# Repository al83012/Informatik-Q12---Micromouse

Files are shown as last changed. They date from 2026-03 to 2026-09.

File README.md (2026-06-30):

# Informatik-Q12---Micromouse

## Ziel
Als Teil des Lehrplans des Leistungsfachs Informatik ist in der Q12 ein Gruppenprojekt vorgesehen. 

Wir haben dafür das Thema `Micromouse` gewählt, versuchen also ein unbekanntes Labyrinth möglichst schnell mit einem kleinen Roboter zu lösen.

## Aufbau
Da es sich hierbei um ein Gruppenprojekt handelt, haben wir uns dafür entschieden, nicht dem typischen Ansatz für Micromice zu folgen und stattdessen das Projekt über mehrere Geräte aufzuteilen. Dadurch ergeben sich Grob 4 Arbeitsbereiche für dieses Projekt:

### Elektronik
- Das Design der Micromouse selbst
- PCB-Erstellung
- Komponenten Wahl und Zusammenbau

### Micromouse Programmierung
- Steuercode der Motoren
- Verarbeitung von Befehlen
- Lokalisierung

### Backend Programmierung
- Kommunikation mit Frontend und Micromouse
- Anwenden bestimmter Lösungsstrategien
- Vorausplanung zur Reduktion von Kommunikation und Latenz
- Erkennen von Mess- und Bedienungsfehlern

### Frontend Programmierung
- Darstellung des Projekts mithilfe einer Website
- Darstellung der Backend-Prozesse
- Eingabe für Lösungsstrategien und Nutzer-Befehlen

### Sponsoring
Wir möchten uns außerdem herzlichst bei den folgenden Sponsoren bedanken:

`Dr. Fritz Faulhaber GmbH & Co. KG` Für das Bereitstellen der Motoren. <br>
`JLCPCB` Für das Bereitstellen der PCBs

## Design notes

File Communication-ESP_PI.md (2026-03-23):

Generell
- WiFi host = Raspberry Pi, kein externes WiFi
- MQTT broker = Mosquitto auf dem Pi
- Pi selbst --> Hostet zwar broker, ist aber auch Client
- Keine Nachricht darf auf das ankommen von Nachrichten in anderen Kanälen angewiesen sein
- QoS 2, um Ordnung innerhalb von Kanälen zu garantieren, und Befehlsanzahl einzuhalten --> Aber: Höhere Latenz

Raspberry Pi
- Auto-startup --> Std Port 1883 --> unverschlüsselt reicht
- hostapd --> Pi als Access Point konfigurieren
  https://raspberrypi.stackexchange.com/questions/88214/setting-up-a-raspberry-pi-as-an-access-point-the-easy-way/88234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
- dhcpcd
  - .conf --> Statische ip-adresse für Host setzen --> Normalerweise 192.168.4.1
  - .conf --> DHCP für wlan0 eingebaute Schnittstelle hinzufügen
- dnsmasq
  - .conf --> Bearbeitet IP-Addresszuweisung für wlan0
  - .conf --> Address-Bereich für verbundene Geräte definieren

### Kommunikationsprotokoll
- Es gibt keinen guten Weg, Verbindungsabbruch durch ausschalten des ESP32 festzustellen --> Man braucht periodische Nachrichten, die erkennen, wann die Verbindung abbricht
- Es ist nicht sicher, dass Nachrichten ankommen --> Alle Informationen, die für eine Nachricht wichtig sind müssen in dieser Nachricht sein
- Der PI muss sicher Nachrichten an den ESP32 schicken können andersherum ist es nicht so dramatisch --> Die Nachrichten des PI müssen nummeriert werden
- Der PI braucht acknowledgements für alle Bewegungen
- Separate Komponenten der Befehle sollten für die einfache Erkennbarkeit durch einfache leerzeichen getrennt werden
#### CMD (vom PI)
- <CMD_ID> ist ein u32
- Bewegungsbefehl: `MOVE #<CMD_ID> <N>` --> N Felder Forwärts; N ist ein u8
- Bewegungsbefehl mit Messungen:
  `MOVE #<CMD_ID> <N> MEASURE <Measurement_Tasks>`
- <Measurement_Task>s (Nur als Teil eines Bewegungs-Befehls):
  `<N>_<L/R/F>_<CONTINUE/STOP-IF-OPEN/STOP-IF-BLOCKED>` --> Beim Nten Teilschritt der Bewegung links, rechts oder forwärts Distanz prüfen und schicken; Falls Continue --> Einfach weiterfahren, sonst entweder stoppen, weil dort direkt eine Wand ist, oder, weil dort keine Wand ist
- Statt einer Zahl kann bei dem Teilschritt auch `X` stehen (Also `X_<L/R/F>_<CONTINUE/STOP-IF-OPEN/STOP-IF-BLOCKED/TURN-IF-BLOCKED>`), wodurch das Measurement jeden Schritt durchgeführt wird
- Drehungsbefehl: `TURN #<CMD_ID> <X>` --> 0 = Keine Drehung; X = Ganzzahl => Zahl * 90° links (neg. = rechts)
- `TURN #<CMD_ID> <X> MEASURE <Measurement_Task>s` --> N der Interrupts ist 0 am Anfang und wächst pro 90° um 1
- Bewegungs-Interrupts des Schrittes "0" sind auszuführen, bevor die Bewegung überhaupt angefangen hat
- **WICHTIG**: Bei Interrupts kann es gut zu einem Overshoot führen, bei dem die Micromouse erst realisiert, dass sie anhalten muss, wenn sie an dieser Stelle schon vorbei ist; Dafür wäre es bei einem PID Controller wichtig, auch diesen Overshoot auszugleichen

#### DBG (vom ESP32)
- `DBG <Nachricht>` --> Wird an Frontend weitergeleitet, darf keine $ enthalten --> würden Nachricht frühzeitig beenden

#### MEASUREMENT (vom ESP32)
- Wird immer geschickt, bevor das zu einer Bewegung gehörende Bewegungs-Ack kommt
- <CMD_ID> ist derselbe u32, der vorher bei der Bewegungs-Anweisung geschickt wurde, die zu der Messung geführt hat
- `MEASUREMENT #<CMD_ID> <N>_<L/R/F> <DEPTH>` --> DEPTH ist 0, falls direkt eine Wand ist, je 1 größer, wenn 1 Zelle weiter leer ist
- `MEASUREMENT #<CMD_ID> <N>_<L/R/F> <DEPTH> SENSORLIMIT` --> Mindestens die Tiefe wurde erreicht, Sensor kann nicht zuverlässig weiter schauen

#### CMD-FINISHED (vom ESP32)
- <CMD_ID> wieder derselbe von davor
- CMD-FINISHED wird immer nach jedem MEASUREMENT geschickt, der von einem CMD verursacht wird
- `CMD-FINISHED #<CMD_ID>` --> Befehl vollständig ausgeführt
- `CMD-FINISHED #<CMD_ID> <N>_<L/R/F>_<STOP-IF-OPEN/STOP-IF-BLOCKED>` --> Frühzeitig beendeter Befehl + Begründung

#### DESYNC (vom ESP32)
- Geschickt, falls eine CMD_ID nicht in 1er-Schritten hochzählt --> eine Nachricht wurde nicht empfangen
- `DESYNC #<CMD_ID> #<CMD_ID> ...` --> Gibt alle CMD_IDs an, die Übersprungen wurden
- Falls ein DESYNC passiert, soll der ESP32 den frühzeitig geschickten Befehl nicht ausführen und stattdessen darauf warten, dass die verlorenen Commands geschickt werden (ohne Garantie für Reihenfolge diesmal, soll einfach warten, bis alle von ihnen da sind)

#### STOP (vom ESP32)
- `STOP` --> Knopf oder ähnliches an ESP32 wurde gedrückt --> Pathfinding beendet, jetzt kann man die micromouse wieder manuell an den Start setzen
- Wird auch beim Startup vom ESP32 geschickt, um zu signalisieren, dass es keinen internen State mehr gibt (z.B. nach Stromverlust)

#### RESTART (vom ESP32)
- `RESTART` --> Knopf oder ähnliches nochmal gedrückt --> Nutzer garantiert, dass sich die micromouse wieder am Start befindet

#### BATTERY (vom ESP32)
- `BATTERY <X>` --> X= pos. Ganzzahl zwischen 0 und 100 --> Batterie in Prozent

### Bsp

(`<` bedeutet zu dem ESP32, `>` bedeutet zu dem PI)

#### Simple Bewegungen, nacheinander

```msgs
< MOVE #0 2
> CMD-FINISHED #0
< TURN #1 1
> CMD-FINISHED #1
< MOVE #2 1
> CMD-FINISHED #2
< TURN #3 -1
> CMD-FINISHED #3
```

#### Simple Bewegungen, batched

```msgs
< MOVE #0 2
< TURN #1 1
< MOVE #2 1
< TURN #3 -1
> CMD-FINISHED #0
> CMD-FINISHED #1
> CMD-FINISHED #2
> CMD-FINISHED #3
```

#### Simple Bewegungen mit Measurements

```msgs
< MOVE #0 4 MEASURE 1_L_CONTINUE 2_R_CONTINUE
> MEASUREMENT #0 1_L 2
> MEASUREMENT #0 2_R 3 SENSORLIMIT
> CMD-FINISHED #0
```

#### Simple Bewegungen mit ungenutzten Interrupts

```msgs
< MOVE #0 4 MEASURE 1_L_STOP-IF-OPEN 2_R_STOP-IF-OPEN
> MEASUREMENT #0 1_L 0
> MEASUREMENT #0 2_R 0
> CMD-FINISHED #0
```

#### Simple Bewegungen mit genutzten Interrupts

```msgs
< MOVE #0 4 MEASURE 1_L_STOP-IF-OPEN 2_R_STOP-IF-OPEN
> MEASUREMENT #0 1_L 2
> CMD-FINISHED #0 1_L_STOP-IF-OPEN
```

#### Simple Bewegungen, mit Interrupts und Immer-Measure 

```msgs
< MOVE #0 4 MEASURE X_L_STOP-IF-OPEN$
> MEASUREMENT #0 0_L 0
> MEASUREMENT #0 1_L 0
> MEASUREMENT #0 2_L 3
> CMD-FINISHED #0
< TURN #1 1
> CMD-FINISHED #1
```

#### Simple Bewegungen, mit Interrupts und Immer-Measure + Reingemischte periodische Vorgänge

```msgs
< MOVE #0 4 MEASURE X_L_STOP-IF-OPEN
> MEASUREMENT #0 0_L 0
> MEASUREMENT #0 1_L 0
> MEASUREMENT #0 2_L 3
> BATTERY 76
> CMD-FINISHED #0
< TURN #1 1
> CMD-FINISHED #1
```

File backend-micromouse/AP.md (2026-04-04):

RaspberryPi -> `arne_lender@micromouse-pi`

Als AccessPoint konfigurieren:
[Guide](https://www.raspberrypi.com/tutorials/host-a-hotel-wifi-hotspot/)

- über `ssh arne_lender@micromouse-pi` mit RP über Router verbinden
- `nmcli device` --> Auflisten der Verbindungen
- `eth0` muss verbunden sein, weil sonst beim Rekonfigurieren die Verbindung über ssh abbricht
- `sudo nmcli device wifi hotspot ssid <hotspot name> password <hotspot password> ifname wlan0`
- Hier: `micromouse-pi-hotspot` und `12345678` (Weil Sicherheit nicht das höchste Ziel ist)
- `ssh arne_lender@micromouse-pi.local`
- `nmcli connection` --> Sollte Hotspot zeigen
- `sudo nmcli connection modify <hotspot UUID> connection.autoconnect yes connection.autoconnect-priority 100`

Oder anderer [Guide](https://raspberrypi-guide.github.io/networking/create-wireless-access-point)

- Evtl. falls dhcpcd nicht gefunden wird --> via `sudo apt-get install dhcpcd` clean install

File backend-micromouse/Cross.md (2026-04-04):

# Cross-compilation für den RaspberryPi

Für cross-compilation für den Raspberry Pi sind einige Voraussetzungen erforderlich (Für Windows):

Auf Windows:

- Podman installieren
- Docker Desktop installieren
- WSL Ubuntu installieren (`wsl --install`)
- Docker Desktop starten

In WSL:

- `rustup update
cargo install cross --force`
- `cross build --target aarch64-unknown-linux-musl --verbose`
- Falls der Zugriff zu Docker nicht funktioniert: zu Gruppe hinzufügen
  - `sudo usermod -aG docker $USER`
  - Neustart

Der Raspberry PI ist gerade unter "arne_lender@micromouse-pi" zu finden; Verbindung kann via `ssh arne_lender@micrmouse-pi` aufgebaut werden

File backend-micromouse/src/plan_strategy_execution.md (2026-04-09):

# Plan for how to do Strategy Execution

## Goal

- The easiest way would be just waiting for all the measurements to arrive, so that one can guarantee, that `Current World` = `World at end of step`, or in other words: *Since the step is finished, and thus the measurements as well, the World currently stored in memory is the only basis for deciding the next command)
- This is not fully fitting into the program due to 2 important factors:
    - For visualizing maze solvers, it could be nice, to visually not just provide the next step, but also a 'look into the future', which would include going down 'potential' paths and having a branching system
    - One major concern in this speed-based application is latency: By precomputing the next `n` commands, we can have a buffer of size `n`, which would prevent the micromouse from ever having no command at all

## CommandApplication

- The CommandApplication-type represents the execution of a single command given a `starting_world` (`Map` and `Transform`)
- We can use the `potential_result`-type functions to figure out, which termination states are possible (since we only care about termination states for the purposes of deciding the next command (we do not need to consider substeps, which add no further information on their own))
- All `potential_results` are given in the `Requirement`-Form, which means, that they contain a partial map, which is the smallest common multiple of the starting world and the interrupts being on or off: The world is split into two parts:
    - The `Transform`: Is the position of the mouse at the step at which this `potential_result` would terminate
    - The `Map`: Is the minimal map (the one with the fewest 'guesses') possible, which still matches the `starting_world`, but also ensures that all potentially terminating interrupts this command could have triggered before that are off, while the condition the current interrupt needs to terminate (or the end of the command) is on
- This also means, that if a given `starting_world` (or `filter`) forces a command to finish at a certain interrupt (because that which is known about the world triggers the interrupt), it will not continue past this point (since that has been excluded by the command having to finish before that)
- In the context of the `StrategyTree`, the `CommandApplication` is useful for taking an emitted command from a `Node` of the tree (be it the `root` (the best current knowledge, what is going on) or a `potential_result` further down the line) and branching that Node's `Set of potential_results` into another `Set of potential_results` by calling the `potential-result`-function on the command application for every `potential_result` in the `Set of potential_results`(The `starting-states` or the command), which will itself return a `Set of potential_results`,which will all follow the relationship:

```condition
Given a Parent-Child relationship Set(A) --> Set(B) between two nodes:
There exists: a starting state A (A element of Set(A));
There exists: a potential_result of applying a command to that starting state B (B element of Set(B));
Such that:
B is strictly an upgrade of A
```

(Maybe it would be worthwhile to actually keep the sets separate by adding arbitrary identifieres or hashes)

## Strategy Tree

### Building

### Merging

### Pruning

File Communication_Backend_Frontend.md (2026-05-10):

# Messages from backend

## MicromouseManagerEvent

```json
{
    manager_event: <EVENT>,
}
```

### Error

`<EVENT>` =

```json
{
    "MicromouseManagerError": <ERROR>
}
```

- `"ConnectionClosedPermanently"`
  The connection was closed internally (The thread used to run the messaging was dropped, the program exited standard execution and will restart)
- `{"UnknownResponse": {"faulty_text": <TEXT>}}`
  A message received from the micromouse does not match the formatting guidelines / could not be read
- `"CmdConfirmThenRequested"`
  Indicates an error in the Desync-Communication: The execution of a command was confirmed to have started, but then a request to resend that command arrived
- `{"CmdStartBeforeFinish": {"new_cmd": <COMMAND_ID>, "unfinished_cmd": <COMMAND_ID>}}`
  The micromouse sent the signs of starting a new command, but never confirmed finishing the last command that was started
- `{"CmdNotKnown": <COMMAND_ID>}`
  The start of a command was confirmed, but the command id is unknown to the backend
- `"MeasurementWithoutAssociatedCmd"`
  Tried to transform a Measurement to the current position of the micromouse, but the current command was empty internally
- `{"CmdTooLong": <COMMAND_ID>}`
  Tried to process a measurement, but the given measurement-step exceeds the maximum number of steps that command could have performed
- `{"ImpossiblePosition": <COMMAND_ID>}`
  The position which was calculated for the micromouse at the current moment is impossible as it is outside map bounds

### UpdatePosition

//TODO

### UpdatedMap

//TODO

### STOP

`<EVENT>` = `"Stop"`

A Stop was triggered (may be restarted (requires manual resetting to start square) or continued)

### RESTART

`<EVENT>` = `"Restart"`

A Restart was triggered; It should have been manually ensured, that the micromouse is correctly oriented in the starting square

### Finished Command

`<EVENT>` =

`{"FinishedCommand": {"cmd_id": <COMMAND_ID>, "require_new": <REQUIRE_NEW>}}`
  Just received the feedback from the micromouse that a command with the given command id was finished, if require_new is `true`, it indicates that the internal command queue of the micromouse is empty and it will need a new command before it can do anything

# Messages from frontend
## StrategyChange

```json
{
    "StrategyChange": <StrategyChange>
}
```
`<StrategyChange>` = 
```json
{
    "set_position" : <POSITION>, //OPTIONAL, overwrites the current position (in cases of reset etc.)
    "reset_map" : boolean, //If true, resets the map (Making the micromouse forget what it has seen, but not its position)
    "set_strategy" : <STRATEGY_CONFIG>, //OPTIONAL, the new strategy to start
    "set_goal" : <GOAL_POSITION> //OPTIONAL, overwrites the goal position
}
```

`<POSITION>` =
```json
{
    "x": u32,
    "y": u32
}
```

### Strategy Config
`<STRATEGY_CONFIG>` = 
```json
    { <CONFIG_NAME> : <CONFIG> }
```

#### DepthFirst
`<CONFIG_NAME> = "DepthFirstConfig"`
`<CONFIG>` =
```json
{
    "forward_first" : boolean // Whether the path without turns should be preferred (instead of random order)
}
```

#### BreadthFirst
...
#### DbgKnownPath
Usecase: Is reliant on a path from the current pos to the goal already existing; Use for returning to the starting square for instance; Beware to not reset the map
`<CONFIG_NAME> = "DbgKnownPathConfig"`
...

#### FloodFill
...

#### FollowWall
...

#### RandomMove
...

## Pause
```json
"Pause"
```

Pause execution, but do not stop the strategy tree

## Continue
```json
"Continue"
```

Unpause execution, but also maintain the previous state

## Cancel
THERE IS NO CANCEL; IT SHOULD BE DONE VIA A STRATEGY CHANGE

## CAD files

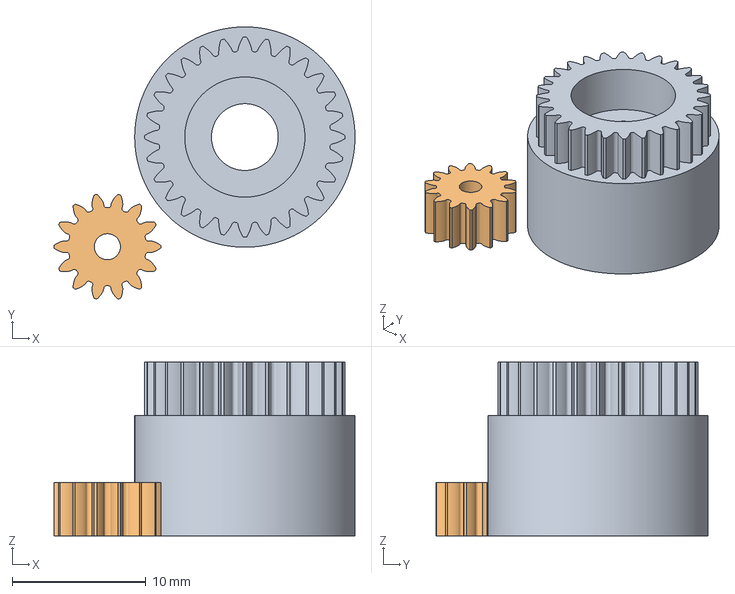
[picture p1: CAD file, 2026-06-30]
3DP/3DP_Tire_Construction.3mf
22.5 x 20.4 x 13.0 mm
3DP_Tire_Construction.stl
Spur Gear 14 teeth.stl

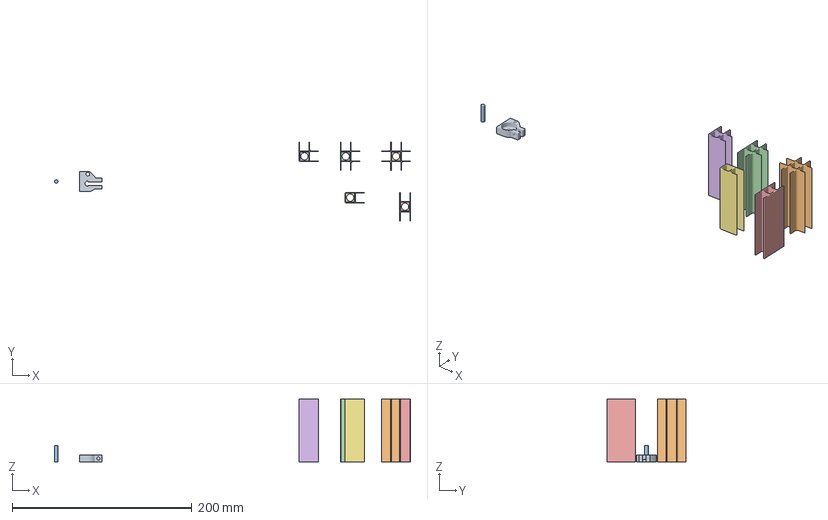
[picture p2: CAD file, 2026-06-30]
3DP/MotorMount.3mf
395.7 x 88.0 x 70.0 mm
MotorMount.stl
X Section.stl
WheelAxis.stl
T Section.stl
Full StraightSection.stl
Corner Section.stl
End Section.stl

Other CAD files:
3DP/Full StraightSection.stl
3DP/LargeGear-Wheel.stl
web-interface/web_frontend/info/3d_model/out.stl
3DP/SmallGear.stl
3DP/MotorBaseSurface.stl
3DP/Micromouse_Faulhaber v17.stl
3DP/T Section.stl
3DP/ToF_Stand-High.stl
3DP/Corner Section.stl
3DP/InnerWheelSpacer.stl
3DP/ToF_Stand.stl
3DP/X Section.stl
3DP/End Section.stl
3DP/SlidingSurface.stl
3DP/Gears - X1C.gcode.3mf
3DP/OuterWheelSpacer.stl
3DP/3DP_Tire_Construction.stl
3DP/LED_Holder-45.stl
3DP/LED_Holder-Fwd-2Cells.stl
3DP/LED_Holder.3mf
3DP/LED_Holder.stl
3DP/MotorClamp.stl
3DP/MotorMount.stl
3DP/OuterWheelSpacer - AxisSide.stl
3DP/OuterWheelSpacer - WheelSide.stl
3DP/Spur Gear 14 teeth.stl
3DP/WheelAxis.stl

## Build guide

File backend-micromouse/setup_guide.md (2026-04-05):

# Raspberry Pi Headless + AP + Rust Cross-Compile Setup Guide

* Configure Raspberry Pi as a WiFi Access Point
* Cross-compile Rust code from Windows (via WSL)
* Transfer binaries over SSH
* Run automatically on boot (console-only)

---

# 1. Base Raspberry Pi Setup

## Enable SSH

```bash
sudo raspi-config
```

→ Interface Options → SSH → Enable

---

## Boot to Console (no GUI)

```bash
sudo raspi-config
```

→ System Options → Boot / Auto Login → Console (no GUI)

Or manually:

```bash
sudo systemctl set-default multi-user.target
```

---

# 2. Configure Raspberry Pi as Access Point

## Install required packages

```bash
sudo apt update
sudo apt install hostapd dnsmasq -y
```

Stop services for now:

```bash
sudo systemctl stop hostapd
sudo systemctl stop dnsmasq
```

---

## Configure static IP

Edit:

```bash
sudo nano /etc/dhcpcd.conf
```

Add:

```text
interface wlan0
static ip_address=192.168.4.1/24
nohook wpa_supplicant
```

---

## Configure DHCP server

Backup original config:

```bash
sudo mv /etc/dnsmasq.conf /etc/dnsmasq.conf.orig
```

Create new:

```bash
sudo nano /etc/dnsmasq.conf
```

```text
interface=wlan0
dhcp-range=192.168.4.2,192.168.4.20,255.255.255.0,24h
```

---

## Configure Access Point

```bash
sudo nano /etc/hostapd/hostapd.conf
```

```text
interface=wlan0
driver=nl80211
ssid=MicromousePi
hw_mode=g
channel=7
wmm_enabled=0
macaddr_acl=0
auth_algs=1
ignore_broadcast_ssid=0
wpa=2
wpa_passphrase=yourpassword
wpa_key_mgmt=WPA-PSK
rsn_pairwise=CCMP
```

---

## Link config

```bash
sudo nano /etc/default/hostapd
```

Set:

```text
DAEMON_CONF="/etc/hostapd/hostapd.conf"
```

---

## Enable services

```bash
sudo systemctl unmask hostapd
sudo systemctl enable hostapd
sudo systemctl enable dnsmasq
```

Reboot:

```bash
sudo reboot
```

---

## Connect from PC

Connect to:

```
SSID: MicromousePi
IP:   192.168.4.1
```

---

# 3. Rust Cross Compilation (Windows + WSL)

## Install WSL

```powershell
wsl --install
```

---

## Inside WSL

Install dependencies:

```bash
sudo apt update
sudo apt install build-essential curl git docker.io -y
```

---

## Install Rust

```bash
curl https://sh.rustup.rs -sSf | sh
source $HOME/.cargo/env
```

---

## Install cross

```bash
cargo install cross
```

---

## Build for Raspberry Pi

### For 64-bit OS:

```bash
cross build --release --target aarch64-unknown-linux-gnu
```

### (Optional) Static binary:
(PREFERRED --> fewer points of error)

```bash
cross build --release --target aarch64-unknown-linux-musl
```

---

# 4. Transfer Binary via SSH

From Windows (PowerShell):

```bash
scp target/aarch64-unknown-linux-gnu/release/backend-micromouse pi@192.168.4.1:/home/pi/
```

---

## Run manually

```bash
ssh pi@192.168.4.1
chmod +x backend-micromouse
./backend-micromouse
```

---

# 5. Automate WiFi Switching + Deploy

## PowerShell Script Example

```powershell
$piSSID = "MicromousePi"

# Save current WiFi
$currentSSID = (netsh wlan show interfaces |
    Select-String '^\s*SSID\s*:\s*(.+)$').Matches.Groups[1].Value.Trim()

# Connect to Pi
netsh wlan connect name=$piSSID
Start-Sleep -Seconds 5

# Upload + run
scp backend-micromouse pi@192.168.4.1:/home/pi/
ssh pi@192.168.4.1 "chmod +x backend-micromouse && ./backend-micromouse"

# Reconnect previous WiFi
if ($currentSSID -and $currentSSID -ne $piSSID) {
    netsh wlan connect name="$currentSSID"
}
```

---

# 6. Auto-start Program on Boot (Console)

Edit:

```bash
nano ~/.bash_profile
```

Add:

```bash
if [ "$(tty)" = "/dev/tty1" ] && [ -z "$SSH_CONNECTION" ]; then
    while true; do
        /home/pi/backend-micromouse
        echo "Program crashed. Restarting..."
        sleep 2
    done
fi
```

---

## Result

On boot:

* Pi shows console on HDMI
* Program runs automatically
* Output visible directly
* Restarts if it crashes

---

# 7. (Optional) Control Onboard LEDs

Disable trigger:

```bash
echo none | sudo tee /sys/class/leds/led0/trigger
```

Control:

```bash
echo 1 | sudo tee /sys/class/leds/led0/brightness
echo 0 | sudo tee /sys/class/leds/led0/brightness
```

---

# 8. Debugging Tips

## Check architecture

```bash
uname -m
file backend-micromouse
```

---

## Check logs

```bash
dmesg
```

---

## Test binary

```bash
./backend-micromouse
```

---

# Final Setup Summary

* Pi acts as WiFi Access Point
* PC connects directly to Pi
* Rust builds via WSL + cross
* Binary sent via SCP
* Program auto-runs on boot
* Output visible on HDMI console

---

# Optional Improvements

* Use static builds (`musl`) for portability
* Add LED status indicators
* Implement remote logging
* Add watchdog / health checks

---

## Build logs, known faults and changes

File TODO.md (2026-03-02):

# TODO
Generell:
  - [ ] Größe festlegen
  - [ ] Materialliste
  - [ ] Interfaces bestimmen
  - [ ] Start-bat oder so? --> Irgendeine Datei, die wir bei Startup aufrufen können, die Website, browser und backend hochfährt?

Frontend
  - [ ] ?

ESP32
  - [ ] ?

Hardware
  - [ ] ?

Backend
  - [ ] Strategy interface
  - [ ] Mouse interface --> Implementiert durch standard Websocket und Testmaus
  - [ ] Search algorithms
  - [ ] Map-struct --> "discovery"
  - [ ] Command queue + interrupts
  - [ ] Action queue
  - [ ] Networking
  - [ ] Compile-Flag für Testmode

Extra
- [ ] Dani? --> Solange es keine physische Micromouse gibt? --> Kann man schon mit der ESP-Programmierung anfangen?
- [ ] Alternativ: In Python oder so: Testmaus --> Irgendetwas, was intern die Map schon kennt und Testweise die Ausführung von Backend-Befehlen und das Feedback simulieren kann

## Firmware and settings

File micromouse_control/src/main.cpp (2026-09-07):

#include "Arduino.h"
#include "WiFi.h"
#include "ArduinoWebsockets.h"
#include "HTTPClient.h"

#include "utility.h"
#include "master.h"
#include "network.h"
#include "handler.h"
#include "Components/Esp32.h"
#include "components/tpl0102.h"
#include "components/tmp464.h"
#include "measurement.h"
#include "Components/drv8424.h"
#include "measurement.h"
#include "driveControl.h"
#include "i2ctool.h"
#include "colors.h"

using namespace COLORS;


void setup() {
delay(1000);
log_i("# Initializing Setup");
Esp32::initESP32();
// Network::setup();

 I2CTOOL::I2CScanner();

 TPL0102::DbgPrintVoltages();
 TMP464::DbgPrintTemperatures(); 


 log_i(GREEN "# Setup done!");
 /* DEBUG: PID-Controller:
 DRIVECONTROL::forward(30, 5);*/

Measurement::IR::calibration::initCalibration(15);





//DRIVECONTROL::simpleForward1(20, 5);
//DRIVECONTROL::forward(20, 5);

}

void loop() {
 //Network::checkNetwork();
 delay(500);
 log_d(".");
 TMP464::DbgPrintTemperatures();
 //Measurement::Sensors::reportTemperature();
 DRV8424::debugPrintEncoderCounts();


Measurement::IR::debugPrintRawDistance(1);

Measurement::IR::debugPrintRawDistance(0);

Measurement::IR::debugPrintRawDistance(2);

Measurement::IR::debugPrintRawDistance(3);





Measurement::IR::WallDetection::debugPrintWallDetectionStatus();







}

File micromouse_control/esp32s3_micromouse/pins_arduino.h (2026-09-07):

#ifndef Pins_Arduino_h
#define Pins_Arduino_h

#include <stdint.h>
#include "soc/soc_caps.h"

#define USB_VID 0x303a
#define USB_PID 0x1001


/*
// Some boards have too low voltage on this pin (board design bug)
// Use different pin with 3V and connect with 48
// and change this setup for the chosen pin (for example 38)
#define PIN_NEOPIXEL        48
// BUILTIN_LED can be used in new Arduino API digitalWrite() like in Blink.ino
static const uint8_t LED_BUILTIN = SOC_GPIO_PIN_COUNT+PIN_NEOPIXEL;
#define BUILTIN_LED  LED_BUILTIN // backward compatibility
#define LED_BUILTIN LED_BUILTIN  // allow testing #ifdef LED_BUILTIN
// RGB_BUILTIN and RGB_BRIGHTNESS can be used in new Arduino API neopixelWrite()
#define RGB_BUILTIN LED_BUILTIN
#define RGB_BRIGHTNESS 64


static const uint8_t TX = 43;
static const uint8_t RX = 44;
*/

// DO NOT USE!
static const uint8_t SDA = 8;
// DO NOT USE!
static const uint8_t SCL = 9;

// DO NOT USE!
static const uint8_t SS    = 10;
//static const uint8_t MOSI  = 11;
//static const uint8_t MISO  = 13;

// DO NOT USE!
static const uint8_t SCK   = 12;

/*
static const uint8_t A0 = 1;
static const uint8_t A1 = 2;
static const uint8_t A2 = 3;
static const uint8_t A3 = 4;
static const uint8_t A4 = 5;
static const uint8_t A5 = 6;
static const uint8_t A6 = 7;
static const uint8_t A7 = 8;
static const uint8_t A8 = 9;
static const uint8_t A9 = 10;
static const uint8_t A10 = 11;
static const uint8_t A11 = 12;
static const uint8_t A12 = 13;
static const uint8_t A13 = 14;
static const uint8_t A14 = 15;
static const uint8_t A15 = 16;
static const uint8_t A16 = 17;
static const uint8_t A17 = 18;
static const uint8_t A18 = 19;
static const uint8_t A19 = 20;

static const uint8_t T1 = 1;
static const uint8_t T2 = 2;
static const uint8_t T3 = 3;
static const uint8_t T4 = 4;
static const uint8_t T5 = 5;
static const uint8_t T6 = 6;
static const uint8_t T7 = 7;
static const uint8_t T8 = 8;
static const uint8_t T9 = 9;
static const uint8_t T10 = 10;
static const uint8_t T11 = 11;
static const uint8_t T12 = 12;
static const uint8_t T13 = 13;
static const uint8_t T14 = 14;
*/



// USB: D-,
// Used for programming
// Do not touch!
static const uint8_t USB_DN = 19;
// USB: D+,
// Used for programming
// Do not touch!
static const uint8_t USB_DP = 20;


// I2C_0-Bus: SCL
// Fast I2C
// Clock frequency can be up to 1 MHz (in theory)
static const uint8_t SCL0 = 45;
// I2C_0-Bus: SDA
// Fast I2C
static const uint8_t SDA0 = 48;


// I2C_0-Bus: SCL
// Slow I2C
// Clock frequency can be up to 400 kHz (in theory)
static const uint8_t SCL1 = 35;
// I2C_0-Bus: SDA
// Slow I2C
static const uint8_t SDA1 = 36;


// SPI-Bus: MOSI
static const uint8_t MOSI = 15;
// SPI-Bus: MISO
static const uint8_t MISO = 21;
// SPI-Bus: SCLK
// Clock frequency can be up to 10 MHz (in theory)
static const uint8_t SCLK = 14;
// SPI-Bus: CS
static const uint8_t LSM_CS = 16;



// Interrupt
static const uint8_t BQ_INT = 47;



// Interrupt
static const uint8_t TCAL_DRV_INT = 0;

// PWM
static const uint8_t FAN_EN = 12;

// PWM
static const uint8_t DRV_AIN1 = 17;
// PWM
static const uint8_t DRV_AIN2 = 11;
// PWM
static const uint8_t DRV_BIN1 = 18;
// PWM
static const uint8_t DRV_BIN2 = 10;

// Interrupt
static const uint8_t ENC_A1 = 3;
// Interrupt
static const uint8_t ENC_A2 = 8;
// Interrupt
static const uint8_t ENC_B1 = 46;
// Interrupt
static const uint8_t ENC_B2 = 9;



// Interrupt
static const uint8_t VL_0_INT = 43;
// Interrupt
static const uint8_t VL_1_INT = 39;
// Interrupt
static const uint8_t VL_2_INT = 40;

// Interrupt
static const uint8_t LSM_INT_1 = 44;
// Interrupt
static const uint8_t LSM_INT_2 = 37;

// Interrupt
static const uint8_t IIS_INT = 38;

// Analog
static const uint8_t PD_0 = 7;
// Analog
static const uint8_t PD_1 = 6;
// Analog
static const uint8_t PD_2 = 5;
// Analog
static const uint8_t PD_3 = 4;

// MOSFET Gate
static const uint8_t IRLED_0 = 42;
// MOSFET Gate
static const uint8_t IRLED_1 = 1;
// MOSFET Gate
static const uint8_t IRLED_2 = 41;
// MOSFET Gate
static const uint8_t IRLED_3 = 2;

// GPIO
// Free tu use
static const uint8_t ESP_IO13 = 13;



#endif /* Pins_Arduino_h */

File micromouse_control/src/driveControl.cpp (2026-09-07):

#include "driveControl.h"
#include "Arduino.h"
#include "Components/drv8424.h"
#include "colors.h"

using namespace COLORS;

namespace DRIVECONTROL {
     float kp = 0.6;
     float ki = 0.0;
     float kd = 0.1;

     float integral = 0.0;
     float prevError = 0.0;
     unsigned long prevTime = 0;

     static void resetPID() {
        integral = 0.0;
        prevError = 0.0;
        prevTime = millis();
        log_d("# (DRIVECONTROL) PID reset: integral=%f, prevError=%f, prevTime=%lu", integral, prevError, prevTime);
    }

    static float computePID(float error) {

        unsigned long currentTime = millis();
        float dt = (currentTime - prevTime) / 1000.0; // Zeit in Sekunden
        dt = constrain(dt, 0.001, 1.0);
        log_i(GREEN "Constrained dt: %f seconds" RESET, dt);
        if (dt <= 0.0) return 0.0; // UNREACHABLE: constrain(dt, 0.001, 1.0); (Außerdem ist der Output 0.0 nicht passend)

        // P
        float pTerm = kp * error;

        // I
        integral += error * dt;
        float iTerm = ki * integral;

        // D
        float derivative = (error - prevError) / dt;
        float dTerm = kd * derivative; // Vllt: Constrain auf dem dTerm; Sonst kann eine schnelle Anpassung des target- und damit des error- werts zu plötzlichen Spitzen führen

        prevError = error;
        prevTime = currentTime;
        log_i("# (DRIVECONTROL) PID Computation: P=%f, I=%f, D=%f, Output=%f", pTerm, iTerm, dTerm, pTerm + iTerm + dTerm);
        return pTerm + iTerm + dTerm;
    }

    void setPIDParameters(float kP, float kI, float kD) {
        log_d("# (DRIVECONTROL) Setting PID parameters: Kp=%f, Ki=%f, Kd=%f", kP, kI, kD);
        kp = kP;
        ki = kI;
        kd = kD;
    }


    void resetEncoders() {
        log_d("# (DRIVECONTROL) Resetting encoders...");
        noInterrupts(); 
        DRV8424::encoderCount1 = 0;
        DRV8424::encoderCount2 = 0;
        interrupts();   
        log_d("# (DRIVECONTROL) Encoders reset: encoderCount1=%ld, encoderCount2=%ld", DRV8424::encoderCount1, DRV8424::encoderCount2);
    }

    void simpleForward1(float distanceCm, float baseSpeedPercentage) {
        log_i("# (DRIVECONTROL) Moving (simple1) forward: Distance =" CYAN "%f cm, Base Speed =" MAGENTA "%f%%", distanceCm, baseSpeedPercentage);
        long targetTicks = DRV8424::calculateTargetTicks(distanceCm);
        log_i("# Target-ticks: %d", targetTicks);
        resetEncoders();
        while(true) {
            long currentLeft = DRV8424::encoderCount1;
            long currentRight = DRV8424::encoderCount2;

            if(abs(currentLeft) >= targetTicks && abs(currentRight) >= targetTicks) {
                log_i(GREEN "# Movement finished succesfuly!" RESET);
                DRV8424::setSpeedPercentage1(0);
                DRV8424::setSpeedPercentage2(0);
                break;
            }
            DRV8424::setSpeedPercentage1(baseSpeedPercentage);
            DRV8424::setSpeedPercentage2(baseSpeedPercentage);
            

        }

    }    

    void forward(float distanceCm, float baseSpeedPercentage) {
        log_i("# (DRIVECONTROL) Moving forward: Distance =" CYAN "%f cm, Base Speed =" MAGENTA "%f%%", distanceCm, baseSpeedPercentage);
        long targetTicks = DRV8424::calculateTargetTicks(distanceCm);
        
        resetEncoders();
        resetPID();


        while (true) {
            long currentLeft = DRV8424::encoderCount1;
            long currentRight = DRV8424::encoderCount2;
            
            long averageProgress = (currentLeft + currentRight) / 2;
            if (averageProgress >= targetTicks) {
                break; 
            }


            float error = (float)(currentLeft - currentRight);

            float correction = computePID(error);
            
            DRV8424::debugPrintEncoderCounts();
           
            float speedLeft = baseSpeedPercentage - correction;     
            float speedRight = baseSpeedPercentage + correction;    

            speedLeft = constrain(speedLeft, 0, 10);   
            speedRight = constrain(speedRight, 0, 10); 

            DRV8424::setSpeedPercentage1(speedLeft);    
            DRV8424::setSpeedPercentage2(speedRight);   

            delay(10); 
        }

        DRV8424::setSpeedPercentage1(0);
        DRV8424::setSpeedPercentage2(0);
}


void backward(float distanceCm, float baseSpeedPercentage) {
    log_i("# (DRIVECONTROL) Moving backward: Distance =" CYAN "%f cm, Base Speed =" MAGENTA "%f%%", distanceCm, baseSpeedPercentage);
    long targetTicks = DRV8424::calculateTargetTicks(distanceCm);
    
    DRV8424::encoderCount1 = 0;
    DRV8424::encoderCount2 = 0;
    resetPID();

    while (true) {
        long currentLeft = DRV8424::encoderCount1;
        long currentRight = DRV8424::encoderCount2;
        
    
        long averageProgress = (currentLeft + currentRight) / 2;
        
        if (averageProgress <= -targetTicks) {
            break; 
        }

  
        float error = (float)(currentLeft - currentRight);

        float correction = computePID(error);

      
        float speedLeft = -baseSpeedPercentage - correction;
        float speedRight = -baseSpeedPercentage + correction;

        speedLeft = constrain(speedLeft, -100, 0);
        speedRight = constrain(speedRight, -100, 0);

        DRV8424::setSpeedPercentage1(speedLeft);
        DRV8424::setSpeedPercentage2(speedRight);

        delay(10); 
    }

    DRV8424::setSpeedPercentage1(0);
    DRV8424::setSpeedPercentage2(0);
}

}   

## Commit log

2026-03-13 Update Communication-ESP_PI.md
    Mehr Infos über die Rust-Bibliothek, die ich nutzen will; Es wirkt zumindest so, als könnte ich sie mit Mosquitto zusammen nutzen, da sie selbst nicht vom Broker abhängig ist
2026-03-14 Added some of the main-structs for handling maps and measurements; Not implemented any real control-flow yet --> just the very basis
2026-03-15 Found small bug, took the y-wall, instead of the x-wall in the NegY case
2026-03-15 Added display-print, Also did the updates to the cell-discovery-status I forgot to do earlier
2026-03-18 Small sample program for esp32 to test connection, currently just blink led
2026-03-18 Established connection in both directions: BUT: Write is not yet doing much: The ESP32 recognizes, that there are bytes available and sends them back, but it just keeps sending empty strings. Further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
2026-03-18 Changed the BindToFirst-Connection Config to also accept Ips whose socket is different
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2026-03-21 This current version does not work, it seems that the reconnects are too frequent, they do not complete before the next connection is attempted
2026-03-21 The current multithreaded approach doesn't seem to be working, likely because the TcpConnection is shared across threads
2026-03-21 This now seems to work, with an average confirmation time/ping of about 90ms, which is ok. I definitely need to add a sleep(1) at the end of my program to allow the heartbeat-thread to stop properly;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
2026-03-22 The Arduino library is automatically sending the pong! The previous duplications come from my own code doing the same
2026-03-23 Added: - action "update_sensor" - sensor data to maze header - update requests from front- to back-end - synchronization of changes in back- to front-end
    Updated:
    - action "change_button" to "update_button"
2026-03-23 Added: - color slide animation
    - button state change with animation on frontend
    - button active design
    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
2026-03-23 Updated docs to more closely match the current communication channel; Will probably also add a new Message-Adapter to the Websocket Channel. Also: Removed Alive and Confirm Alive, done by the PingPon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
2026-04-03 Added new code for the sample:
    Now with status LED to better monitor the current connection state; On this board it was pin 48, but it required the solder bridge on the board to be closed.
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2026-04-05 Storing current move to be able to transform a Measurement-Message into an actual absolute measurement
2026-04-07 increased maze size by 2px in width&height ; switched from path-system to basic setup of arm-system
2026-04-07 increased maze size by 2px in width&height ; switched from path-system to basic setup of arm-system ; added some basic comments which where neglected for the entire project
2026-04-07 changed the design of maze ; added more to the arm system
2026-04-07 finished arm system design ; changed init_maze function to use the arm system
2026-04-07 changed reset_maze function to use the arm system
2026-04-08 Added first attempt at having a CommandApplication --> Now I just need to allow for filtering (based on current map / knowledge of another map? (--> If I have an internal known map (for testing purpo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
2026-04-10 Code revamp
    +Rebuilt network code to fit the new websocket model
    +Basic simulation for simple movement, turns and measurements
    +Structured code
    +Organized parameters
    -Removed old network code
    TODO:
    -Create buffer for desyncs
    -Handle movement-stabilization and implement pid-controller
    -Send specific interrupts when stopping
    -Better handling of restarts or resets
2026-04-11 Added visuals for drawing paths -> not yet tested; Also: tried implementing new methods for command_applications to get the beginning of a step (or what it would have to look like) --> Also added err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
2026-04-11 Added some Debugging; ALSO: The formatting the ESP32 uses does not match the guidelines: DEB --> DBG; Other than that: 'MEASUREMENT #0 0' is not enough information, the pattern is 'MEASUREMENT #<CMD_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
2026-04-11 renamed file so that it would be shorter in debug prints (:
2026-04-11 Working ok, but not stepping past where it should go; Also: The esp should send a reason for interrupting
2026-04-12 Updated to have a watch-value to maintain a stable size for the queue; however: it seems, that the handle_read() was interrupted during its execution, which lead the commands to not be processed corr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
2026-04-12 Fixed issue where the manager would lock up the current_command mutex by letting the helper-functions directly borrow the mutex guard from their calling context
2026-04-13 Added a new variable that keeps track of the order in which commands are being processed alongside a new ErrorKind, which will determine errors in ordering / losing commands; Also: Rewrote the map ap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
2026-04-13 Fixed no-measurement situation in parsing messages in the esp32, a more robust solution would be nice in the future
2026-04-13 Cleanup, also: Maybe add a debug print for update-position events as well + Also: could_be_upgrade also reacts when the elements are the same --> But should not be included in DiscoveryMessage
2026-04-18 Added prune-method for rejecting the current commands paths; also I believe that expand_fully should work, but it is not tested yet; Also started adding some utils-methods, as I will need some utils 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
2026-04-18 The first attempt at marking boundaries as visited in the worlds generated by the FilteredCommandApplication did not work, it ignored walls in specific cases; At least I know that my code can catch t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
2026-04-18 Added painted boundaries; makes the maps a lot more readable; the mistake was actually in at_certain_step, as it combined the previous continuing world with the current position without updating the 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
2026-04-18 Added function to let the strategy tree delete the current root and then place its successor in that place; I will need to add some kind of graphics-channel and a send-channel, which can catch when t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
2026-04-19 Marked constants; Removed global task list; Added attachment of interrupts to message;
2026-04-19 wrote move_node_back-fn, still need to add the inser-fn to insert nodes into trees and the merge-logic
2026-04-21 Fixed the wrong parsing of InterruptOccurrence
2026-04-24 Added hyperlink logging to create logs with links for easier debugability, currently only in the testing phase, but the spans are working; Now I will only need to add some macros for span-independent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
2026-05-01 Added instrument to most important methods; Still need to add the fields-dropdown for entering spans; Also: new FilteredCommandApplication didn't work + the ws-read-handles are not yet instrumented i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
2026-05-03 added info page with 3d model: - added styling - added basic 3d models as tests - added buttons for switching between pages
    added gateway ip detection (which doesn't work, idk)
    added color to logging
    fixed a few bugs
    [out.stl]
2026-05-03 Adjusted function for pruning using filter by now also upgrading non-expanded nodes using the map (which could be used by things like the the DepthFirst-Strategy (as it depends on the previouse path 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
2026-05-10 Added new DbgKnownPath Strategy-template: It will be used for finding the way back to the start, when not deleting the visited path --> One next_cmd execution should be enough to fully plan the path;
    Started with the first part of the modify-functionality of the StrategyTreeManager;
    Also: adjusted the conditions under which commands can be sent (Now the next layer also has to be full as we need some grafting layer)
    TODO: Adjust the max_nodes-functionality: The new rules about sending commands could prevent commands to be sent, when the current task has to many children, where max_nodes could prevent the next layer from being sent; This means, that min_layers = 2 is a requirement
2026-05-18 Added Follow-Wall-Strategy using interrupts; It could be interesting to add a follow-wall-strategy which switches wall whenever a loop is encountered
2026-05-18 Not currently compilable, but: Noticed big inconsistency: Whenever we finish a root, it will be replaced by its successor; This successor is either already expanded, will immediately be expanded or c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
2026-05-19 Adapted the strategy_tree's functionality to be used inside the DynStrategyTree; Also rewrote some old parts that did not really match the current state
2026-05-29 Identified part of the issue: Whenever there is just a chain of a bunch of commands which just return CommandFinished and not a Map-Update, there is no update for send
2026-05-29 Unloaded to other threads; Maybe a bit faster; should do some profiling
2026-06-03 Important note: When an interrupt is triggered, that steps other interrupts are not recorded --> A 0-step-move with multiple interrupts could lead to missing out on a measurement that was integrated 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
2026-06-13 Update micromouse_message.rs; Breaking: Added template for new Sensor-Event, but not yet implemented; Also: Added more information on what exactly a Restart entails
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2026-06-17 Added variables to adjust whether to do specific side-interrupts in the seeking-move
2026-06-18 Adjusted the logic of expand_fully --> Previously: increase expanded layers if no previous or the current layer failed expansion (do not allow incomplete layers) and if something was expanded in the 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
2026-06-18 Trying out undefined dfs --> Very promising, but currently gets stuck in specific situation; PROBABLY due to the dead end being right next to the NegX border (--> Difference between Exists(true) and 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
2026-06-20 Removed println that was avoiding the filters on the console fmt layer
2026-06-20 Found error: in some cases, the path_from_start is not being expanded properly; In that case, due to the new intersections not being on the path, the strategy fails and the frontend correctly sends a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
2026-06-30 Fixed previously uncommitted and added 3DP-files to the content
    [3DP_Tire_Construction.3mf, 3DP_Tire_Construction.stl, Corner Section.stl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]
2026-06-30 3DP files added
    [Micromouse_Faulhaber v17.stl]
2026-06-30 Cleaned Lowpoly version
    [Micromouse_Faulhaber v17.stl]
2026-07-02 Adjusted the Frontend Simulator to cover a new test-case: Stopping non-complete strategies; Also: encountered an error: When restarting a StrategyTreeManager which was previously closed (as it was ne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
2026-07-02 Added new variant for the strategy-tree to signify changed meanings: Closed is a valid state in which there is no strategy, but a visual --> It is the initial state; CurrentlyChanging is the state th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
2026-07-02 I believe I encountered part of the error: When grafting the strategy tree, the graft-results may have to have their map reset, however, the new map-update-events are still based on the old map, whic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
2026-07-02 Added the concept of grafting filters; Whenever there is a graft, I define what the branches beyond the graft are allowed to know about and delete information in accordance to that grafting filter; T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
2026-07-03 Changed the way in which grafting is done; There is a separate graftable node layer which is the layer that was not sent, but is full (directly after the sent layers); ALSO: Instead of immediately fi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
2026-07-03 Adjusted the micromouse manager to handle idle states without disconnecting (as tungstenite does not by default return pings); Also: Added Stream-Variable to send keyboard interrupt signals to bind m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
2026-07-04 Added pruning for dead ends to the DFS-Strategy
    [SmallGear.stl]
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2026-07-05 When the first step in a tree is a strategy end, closing the tree currently errors; Shoudl first check for equality before setting sent layer to 0
2026-07-07 Flood fill strategy is fully working; Also added an exploration-incentive which makes exploring new paths more valuable
    [LargeGear-Wheel.stl, SmallGear.stl]
2026-07-10 Added DbgKnownPath as a FloodFill variation, which capsules off all non-explored parts
    [LargeGear-Wheel.stl, MotorBaseSurface.stl, SmallGear.stl]
2026-07-12 fixed a few bugs in PathManager; added a logger for better debugging; added more tests; switched frontend to new change system
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
